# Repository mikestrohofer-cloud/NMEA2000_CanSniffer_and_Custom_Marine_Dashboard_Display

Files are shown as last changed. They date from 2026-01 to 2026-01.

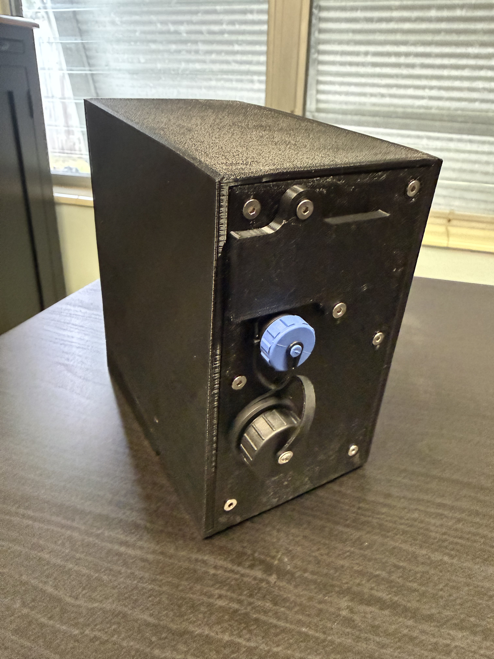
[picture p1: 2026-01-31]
Photos/Display Body 2.jpeg

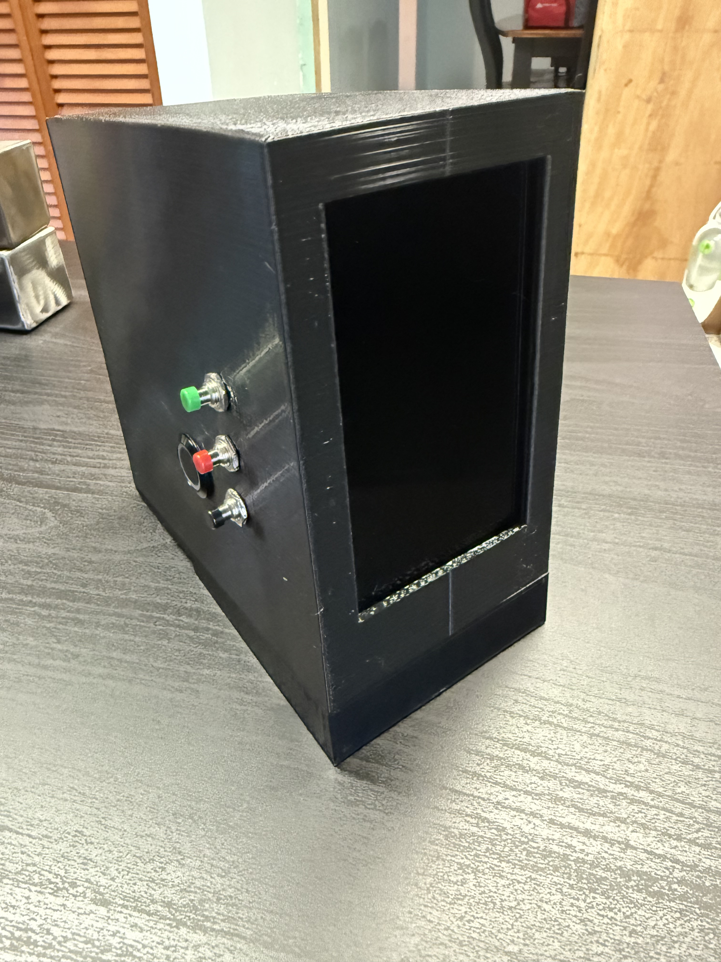
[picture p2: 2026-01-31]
Photos/Display Body 1.jpeg

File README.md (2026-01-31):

# CanSniffer & Mini Screen Build (MK1)

Hi, 

Welcome to CanSniffer & Mini Screen build MK1, this project came from the desire to interact with my boat’s network, sniff data and display on my own custom screen with custom graphics. 
NOTE: This was all ChatGPT vibe coded, I am not a software engineer, I’m more of a 12V electronics / Cad guy who was feeling like trying something new. As a result this code is likely not optimized and not fit for commercial use. Please use it at your own risk and
DO NOT USE THIS HARDWARE OR CODE FOR ANY CRITICAL INSTUMENTATION DISPLAYS

Now that’s out of the way, the system architecture is split into 2 halves, the Arduino based CanSniffer takes the data off the NMEA2000 Network, using a CAN reading card, grabs data out of the relevant PGN’s and finally outputs a CSV string over USB of 4 values that the Pi is expecting to display on the UI.  

Currently it is set up for single frame reading of the Trim % and RPM PGN. It uses fast packet to decode the PGN for fuel consumption rate and it uses FF12 which is proprietary SUZUKI PGN used for shift indication. That PGN was decoded during the DEV process for my specific setup of a single Fly-by-wire shift and throttle controller, one SMG4 MFD and a DF200 single outboard. This may or may not work with other setups of SUZUKI hardware.This is an experimental hobby project, not production-grade, as I said before and chatgpt handled the code work on this project. I recommend having a laptop collecting the log data when using the software. There is also a little I2C OLED screen on the CanSniffer itself you can use for whatever. 

In the PI I have some helper scipts that work with the 3 buttons on the side of the display case, the references to the name of the main code for the pi display is called PiRudderTach.py you can change that but you will have to adjust everything in the support sofware, the screen also needs to be configured in the PI for portait orientation

In my experience this build has been stable and I am happy with it, of course anyone who has more experience will be able to add features or optimizations. Good luck, I would love to hear from anyone who is working on this project and what you end up making. 

## Getting Started
1. Upload the Arduino sketch to an Arduino Nano  
2. Connect MCP2515 to the NMEA2000 backbone  
3. Plug Arduino into Raspberry Pi via USB  
4. Run the dashboard script on the Pi  

This project was developed and tested on:
- Suzuki DF200 outboard
- Single fly-by-wire shift/throttle controller
- One SMG4 MFD
- Arduino Nano + MCP2515 module
- Small I2C OLED screen on the sniffer unit

The current firmware is configured for:
- **Trim % + RPM** (single-frame decoding)
- **Fuel Rate** (Fast Packet decoding, PGN 127489)
- **Shift / Gear Indicator** via proprietary Suzuki PGN:
- **PGN FF12 (65298)** — Suzuki-specific gear data

## Serial Output Format
The Arduino outputs a 4-field CSV frame over USB:

trim_raw,rpm_raw,gear,fuel_gph
Where `gear` is encoded as:
- `-1` = Reverse  
- `0` = Neutral  
- `1` = Forward  

## Licensing
- Software (Arduino + Pi code): GPL v3  
- Hardware/design files (STLs, wiring): CC BY-SA 4.0

This project is for experimental/educational use only.

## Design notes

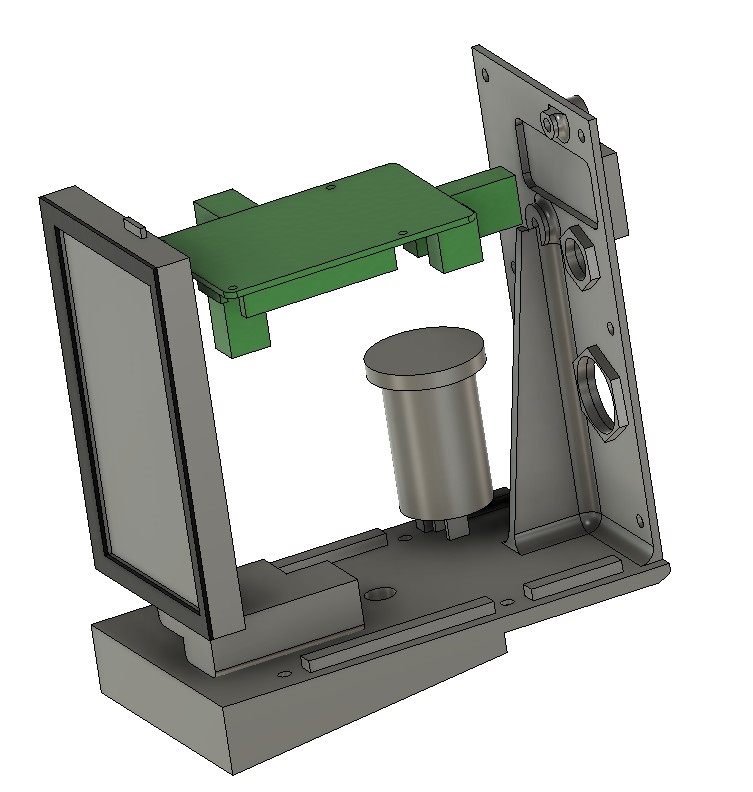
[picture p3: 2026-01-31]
Photos/Mini Screen CAD 2.jpg

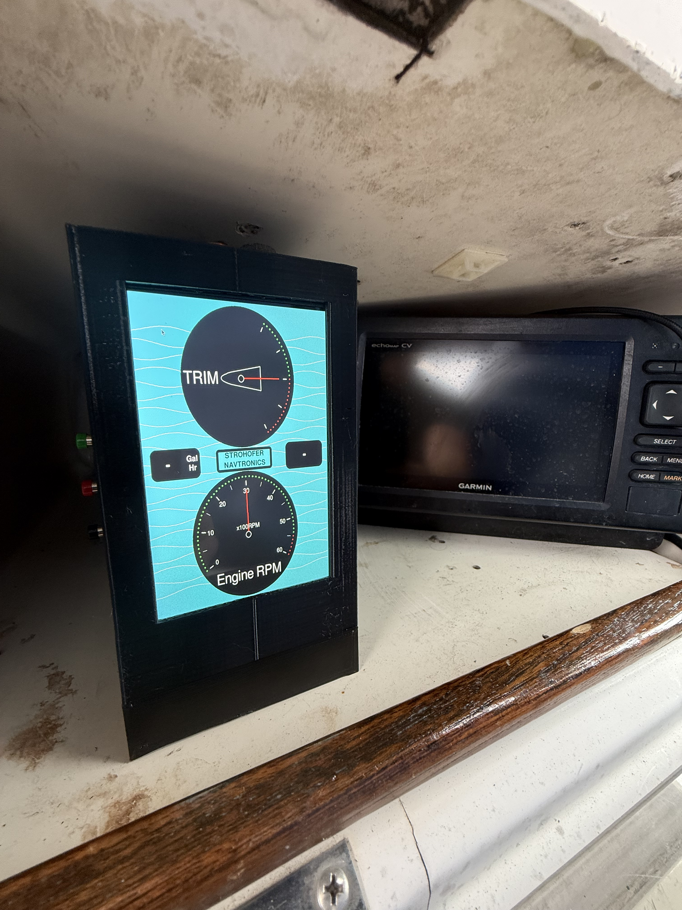
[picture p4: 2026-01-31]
Photos/Display Screen.jpeg

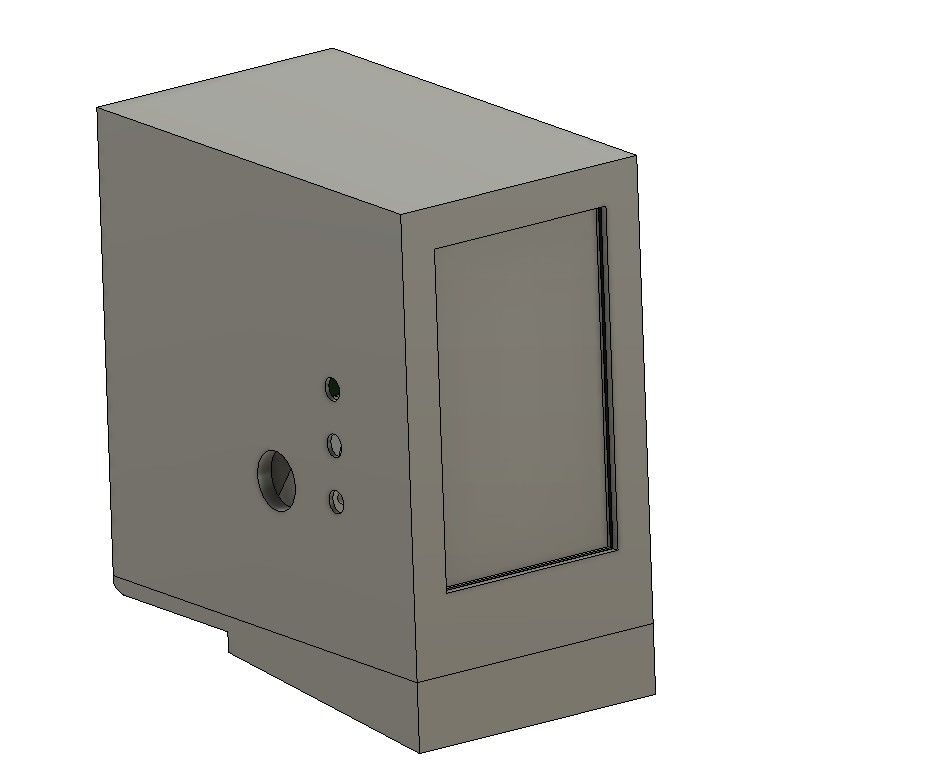
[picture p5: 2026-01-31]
Photos/Mini Screen CAD 1.jpg

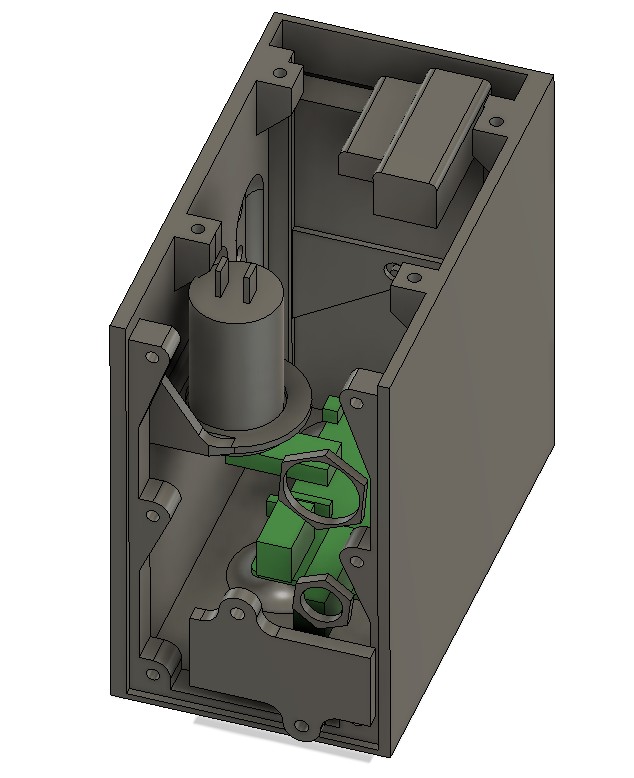
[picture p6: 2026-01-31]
Photos/Mini Screen CAD 3.jpg

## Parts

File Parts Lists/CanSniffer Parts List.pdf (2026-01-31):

# CanSnier Part List

Mini Nano V3.0 ATmega328P

### 5 Pcs 0.96 Inch OLED I2C IIC Display Module 12864 128x64 Pixel SSD1306 Mini Self-

Luminous OLED Screen Board Compatible with Arduino Raspberry Pi

WWZMDiB 3 Pcs MCP2515 TJA1050 CAN Bus Module SPI Interface Compatible with for Arduino Raspberry Pi ESP32 STM (CAN Bus Controller + Receiver)

AITRIP 8 Pack Mini MP1584EN DC-DC Buck Converter Adjustable Power Supply Module 24V to 12V 9V 5V 3VCompatible with Arduino Raspberry Pi

100pcs 5.1K ohm Resistor 1/4w (0.25 Watt) ±1% Tolerance Metal Film Fixed Resistor

DIANN 5pcs USB Type-C Breakout Board Serial Basic Breakout Female Connector Type PCB Converter Board

NMEA2000 Cable (Choose the length you need to get from your T to the can-snier)

QIANRENON 5Gbps USB C Threaded Fixed Short Cable USB Type C 3.0 Male to Female Embedded Charging Data Adapter Cable USB C 3.0 Bulkhead Mount Connector PD 60W 3A, for Furniture/Car/RV, 30cm/11.8in

Fuse Holders (Use a .5 amp)

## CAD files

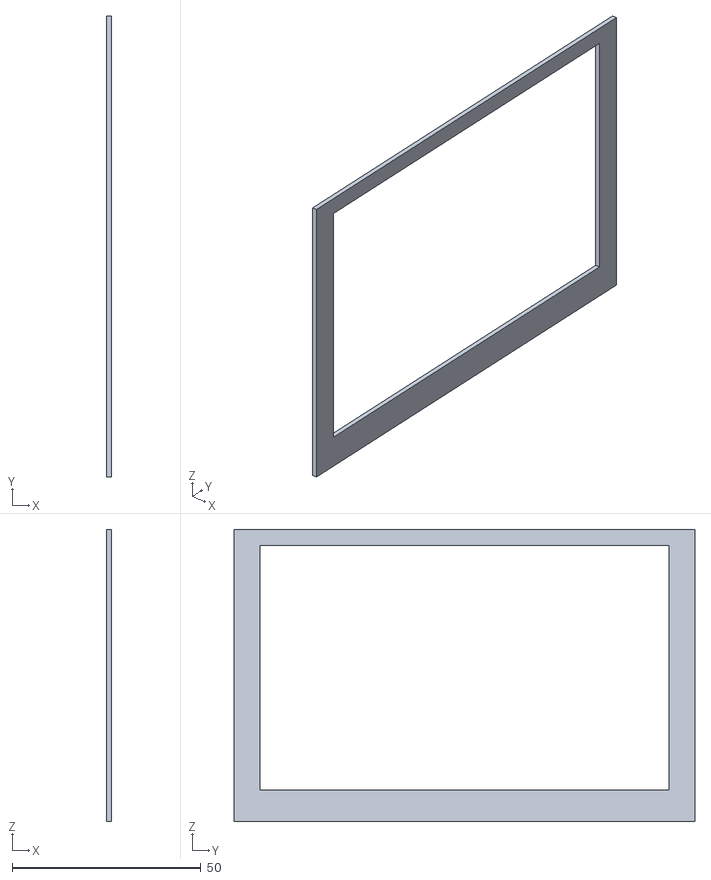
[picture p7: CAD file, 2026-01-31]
3D_Prints/Display Gasket.stl
1.27 x 122.3 x 77.5

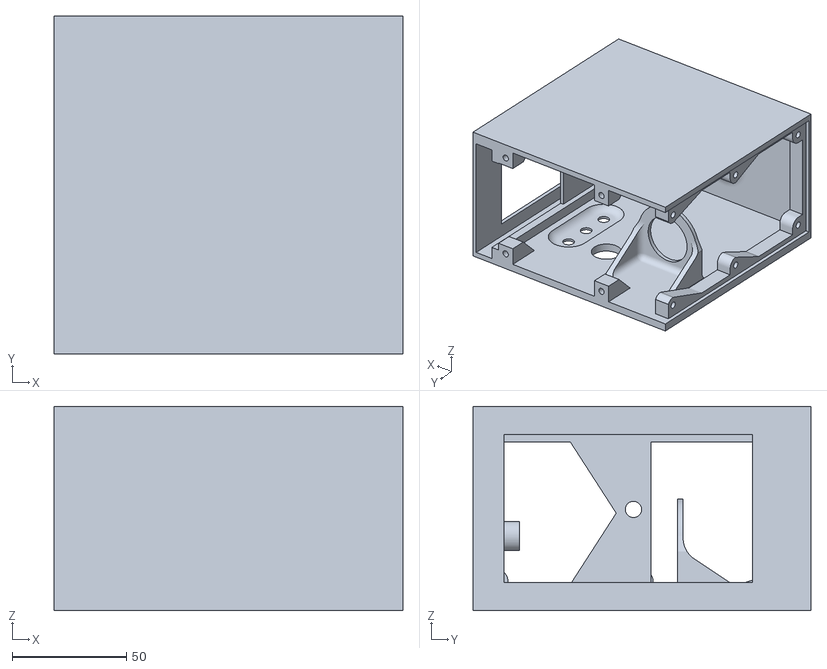
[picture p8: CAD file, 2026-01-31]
3D_Prints/Display Body.stl
152.4 x 147.7 x 89.2

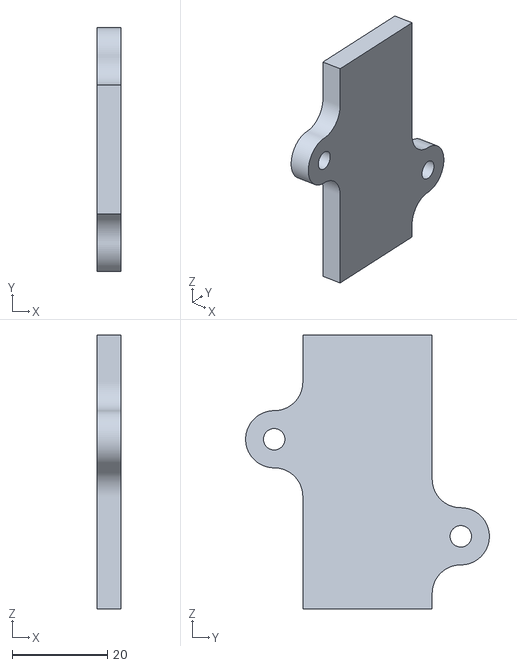
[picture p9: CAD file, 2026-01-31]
3D_Prints/Display PI USB Cover.stl
5.08 x 51.2 x 57.5

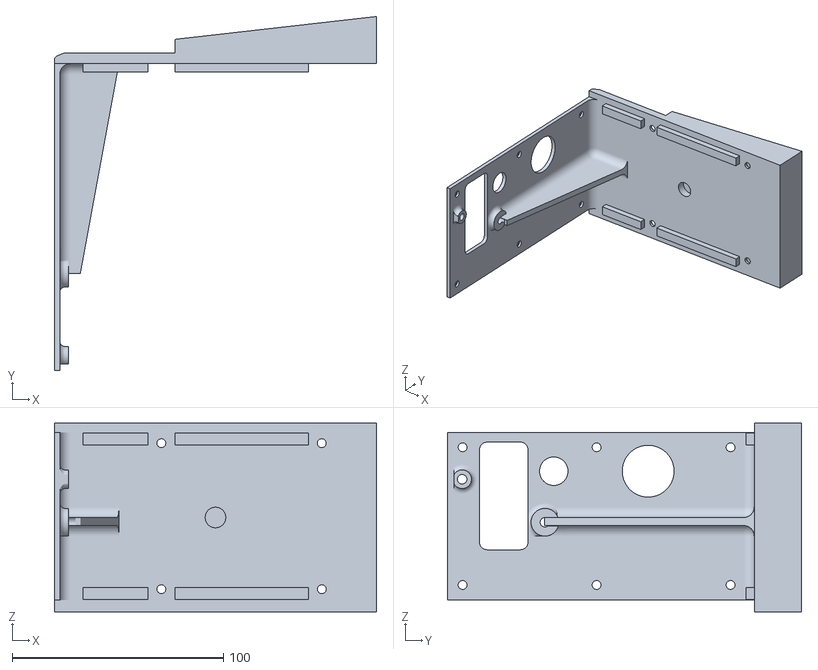
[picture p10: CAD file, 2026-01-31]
3D_Prints/Display Rear Panel.stl
152.4 x 167.5 x 89.2

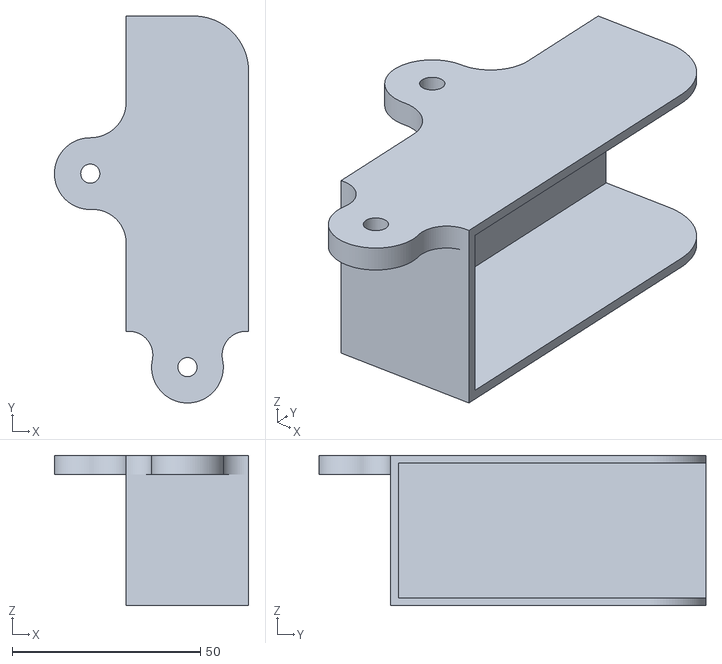
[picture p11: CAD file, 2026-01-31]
3D_Prints/CanSniffer Mount R 3D Print.stl
51.6 x 102.8 x 39.9

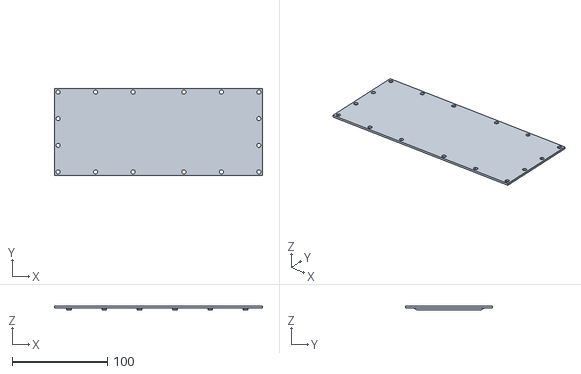
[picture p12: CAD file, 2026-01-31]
3D_Prints/CanSniffer Lid 3D Print.stl
218.4 x 91.4 x 3.81

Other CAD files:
3D_Prints/CanSniffer Mount L 3D Print.stl

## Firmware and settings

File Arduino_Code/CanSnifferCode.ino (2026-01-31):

#include <SPI.h>
#include <mcp_can.h>
#include <U8x8lib.h>

// ================== CONFIG ==================
#define CAN_CS_PIN   10
#define CAN_INT_PIN  2           // MCP2515 INT -> Nano D2
#define CAN_SPEED    CAN_250KBPS
#define CAN_CLOCK    MCP_8MHZ

// OLED text-only (still useful locally)
U8X8_SSD1306_128X64_NONAME_HW_I2C oled(U8X8_PIN_NONE);

// PGNs we care about
static const uint32_t PGN_127489   = 127489UL; // Fuel rate (Fast Packet)
static const uint32_t PGN_SUZ_GEAR = 65298UL;  // Suzuki proprietary (0xFF12)
static const uint32_t PGN_127488   = 127488UL; // Engine params rapid update (you saw trim + RPM here)

// Data freshness (ms)
#define STALE_FUEL_MS 1500UL
#define STALE_GEAR_MS 1000UL

#define OLED_PERIOD_MS 150UL

// CSV output to mini screen
#define CSV_PERIOD_MS 50UL        // 20 Hz
#define CAN_STALE_MS  1000UL      // if CAN stale -> force Neutral / zeroes

// Optional: filter by source address (0xFF = accept any)
#define ENGINE_SA_FILTER 0xFF

// ================== RPM CALIBRATION ==================
// Empirical fix: Suzuki 127488 RPM reads high (~900 shows ~650 actual)
#define RPM_CAL 0.72f

// ================== CAN ==================
MCP_CAN CAN0(CAN_CS_PIN);

// ================== INT FLAG ==================
volatile bool canIntFlag = false;
void onCanInt() { canIntFlag = true; }

// ================== VALUE STATE ==================
volatile float fuel_gph = 0.0f;
volatile char  gearCharV = 'N';      // 'F' 'N' 'R'
volatile uint8_t engine_instance = 0;

volatile int rpm_calibrated = 0;
uint32_t last_rpm_ms = 0;

volatile int trim_percent = -1;      // optional: used for local OLED only
uint32_t last_trim_ms = 0;

uint32_t last_fuel_ms = 0;
uint32_t last_gear_ms = 0;

uint8_t lastSuzB4 = 0x00;

// ================== HELPERS ==================
static inline uint32_t extractPGN(uint32_t canId) {
  uint8_t dp = (canId >> 24) & 0x01;
  uint8_t pf = (canId >> 16) & 0xFF;
  uint8_t ps = (canId >> 8)  & 0xFF;
  uint32_t pgn = ((uint32_t)dp << 16) | ((uint32_t)pf << 8);
  if (pf >= 240) pgn |= ps;
  return pgn;
}

static inline uint8_t extractSA(uint32_t canId) {
  return (uint8_t)(canId & 0xFF);
}

static inline uint16_t u16le(const uint8_t* p) {
  return (uint16_t)p[0] | ((uint16_t)p[1] << 8);
}

static inline int16_t s16le(const uint8_t* p) {
  return (int16_t)u16le(p);
}

// Pi expects: {1:"R", 2:"N", 3:"F"}
static int gearToShiftIndicator(char g) {
  if (g == 'R') return 1;
  if (g == 'N') return 2;
  if (g == 'F') return 3;
  return 2; // safe default Neutral
}

// Suzuki gear decode (proven on your system)
static char decodeSuzukiGearB4(uint8_t b4) {
  if (b4 == 0x7F) return 'N';          // special neutral case
  uint8_t top = b4 & 0xC0;
  if (top == 0xC0) return 'F';
  if (top == 0x80) return 'N';
  if (top == 0x40) return 'R';
  return '?';
}

// ================== 127488 RPM + TRIM ==================
// Note: you're seeing trim% track correctly from this PGN on your Suzuki gateway.
// RPM bytes are standard (bytes 1..2, 0.25 RPM/bit). Trim byte is vendor-ish;
// based on your captures it behaves like 0..100 (byte 5). We'll keep it simple.
static void decode127488_rpm_trim(const uint8_t* d, uint8_t len) {
  if (len < 6) return;

  // RPM: bytes 1..2 little-endian
  uint16_t raw = (uint16_t)d[1] | ((uint16_t)d[2] << 8);
  if (raw != 0xFFFF && raw != 0x7FFF) {
    float rpm = raw * 0.25f;
    rpm *= RPM_CAL;
    rpm_calibrated = (int)(rpm + 0.5f);
    last_rpm_ms = millis();
  }

  // TRIM: based on your logs, byte 5 tracks 0..100-ish.
  // If it ever goes 0xFF, treat as invalid.
  uint8_t t = d[5];
  if (t != 0xFF) {
    trim_percent = (int)t;
    last_trim_ms = millis();
  }
}

// ================== FAST PACKET (127489) ==================
struct FastPacket {
  bool active = false;
  uint8_t sa = 0xFF;
  uint8_t seq = 0;
  uint8_t expectedLen = 0;
  uint8_t buf[32];
  uint8_t filled = 0;
  uint32_t lastMs = 0;

  void reset() { active=false; sa=0xFF; seq=0; expectedLen=0; filled=0; lastMs=0; }

  void begin(uint8_t _sa, uint8_t _seq, uint8_t totalLen, const uint8_t* frame) {
    reset();
    active = true; sa=_sa; seq=_seq; expectedLen=totalLen; lastMs=millis();
    uint8_t toCopy = 6;
    if (toCopy > expectedLen) toCopy = expectedLen;
    for (uint8_t i=0;i<toCopy;i++) buf[i] = frame[2+i];
    filled = toCopy;
  }

  void add(uint8_t _sa, uint8_t _seq, uint8_t frameIdx, const uint8_t* frame) {
    if (!active) return;
    if (_sa != sa) return;
    if (_seq != seq) return;
    lastMs = millis();

    uint16_t base = 6 + (uint16_t)(frameIdx - 1) * 7;
    if (base >= expectedLen) return;

    uint8_t toCopy = 7;
    if (base + toCopy > expectedLen) toCopy = expectedLen - base;
    for (uint8_t i=0;i<toCopy;i++) buf[base+i] = frame[1+i];

    uint16_t newFilled = base + toCopy;
    if (newFilled > filled) filled = (uint8_t)newFilled;
  }

  bool complete() const { return active && expectedLen > 0 && filled >= expectedLen; }
};

FastPacket fp489;

static void decode127489_payload(const uint8_t* p, uint8_t n) {
  if (n < 11) return;
  engine_instance = p[0];

  // Fuel rate at payload offset 9..10, 0.1 L/h signed
  int16_t fuel_raw = s16le(&p[9]);

  // NA guards
  if (fuel_raw == (int16_t)0x7FFF || fuel_raw == -1) return;

  float fuel_Lph = fuel_raw * 0.1f;
  if (fuel_Lph < 0) fuel_Lph = 0;

  fuel_gph = fuel_Lph * 0.264172052f; // L/h -> GPH
  last_fuel_ms = millis();
}

static void handle127489_frame(uint8_t sa, const uint8_t* d, uint8_t len) {
  if (len < 8) return;

  if (fp489.active && (millis() - fp489.lastMs) > 250UL) fp489.reset();

  uint8_t hdr = d[0];
  uint8_t seq = (hdr >> 5) & 0x07;
  uint8_t frameIdx = hdr & 0x1F;

  if (frameIdx == 0) {
    uint8_t totalLen = d[1];
    if (totalLen > sizeof(fp489.buf)) { fp489.reset(); return; }
    fp489.begin(sa, seq, totalLen, d);
  } else {
    fp489.add(sa, seq, frameIdx, d);
  }

  if (fp489.complete()) {
    decode127489_payload(fp489.buf, fp489.expectedLen);
    fp489.reset();
  }
}

// ================== SUZUKI GEAR (65298) ==================
static void decodeSuzukiGear(const uint8_t* d, uint8_t len) {
  if (len < 5) return; // we use d[4]
  lastSuzB4 = d[4];
  char g = decodeSuzukiGearB4(lastSuzB4);
  if (g == 'F' || g == 'N' || g == 'R') {
    gearCharV = g;
    last_gear_ms = millis();
  }
}

// ================== OLED ==================
static void oledBoot(const char* l1, const char* l2) {
  oled.clear();
  oled.drawString(0, 0, l1);
  oled.drawString(0, 2, l2);
}

static void oledRender() {
  uint32_t now = millis();
  bool fuel_stale = (now - last_fuel_ms) > STALE_FUEL_MS;
  bool gear_stale = (now - last_gear_ms) > STALE_GEAR_MS;
  bool rpm_stale  = (now - last_rpm_ms)  > CAN_STALE_MS;

  char line0[17], line2[17], line4[17], line6[17];

  if (fuel_stale) snprintf(line0, sizeof(line0), "FUEL: ---- GPH");
  else {
    int whole = (int)fuel_gph;
    int frac  = (int)((fuel_gph - whole) * 100.0f + 0.5f);
    if (frac < 0) frac = 0;
    if (frac > 99) frac = 99;
    snprintf(line0, sizeof(line0), "FUEL:%d.%02d GPH", whole, frac);
  }

  if (gear_stale) snprintf(line2, sizeof(line2), "GEAR:? RPM:----");
  else {
    char gbuf[2] = { gearCharV, 0 };
    if (rpm_stale) snprintf(line2, sizeof(line2), "GEAR:%s RPM:----", gbuf);
    else snprintf(line2, sizeof(line2), "GEAR:%s RPM:%4d", gbuf, rpm_calibrated);
  }

  // Show trim on line4
  if ((now - last_trim_ms) > CAN_STALE_MS || trim_percent < 0) {
    snprintf(line4, sizeof(line4), "TRIM: --%%  B4:%02X", lastSuzB4);
  } else {
    int tp = trim_percent;
    if (tp < 0) tp = 0;
    if (tp > 100) tp = 100;
    snprintf(line4, sizeof(line4), "TRIM:%3d%% B4:%02X", tp, lastSuzB4);
  }

  snprintf(line6, sizeof(line6), "AGE F:%lu G:%lu",
           fuel_stale ? 9999UL : (unsigned long)(now - last_fuel_ms),
           gear_stale ? 9999UL : (unsigned long)(now - last_gear_ms));

  oled.clear();
  oled.drawString(0, 0, line0);
  oled.drawString(0, 2, line2);
  oled.drawString(0, 4, line4);
  oled.drawString(0, 6, line6);
}

// ================== CAN DRAIN ==================
static void processCAN() {
  unsigned long rxId = 0;
  unsigned char len = 0;
  unsigned char buf[8];

  while (CAN0.checkReceive() == CAN_MSGAVAIL) {
    CAN0.readMsgBuf(&rxId, &len, buf);

    uint32_t id = (uint32_t)rxId;
    uint8_t sa = extractSA(id);
    if (ENGINE_SA_FILTER != 0xFF && sa != ENGINE_SA_FILTER) continue;

    uint32_t pgn = extractPGN(id);

    if (pgn == PGN_127489) {
      handle127489_frame(sa, buf, len);
    } else if (pgn == PGN_SUZ_GEAR) {
      decodeSuzukiGear(buf, len);
    } else if (pgn == PGN_127488) {
      decode127488_rpm_trim(buf, len);
    }
  }
}

// ================== CSV OUTPUT ==================
static void sendCSV() {
  // Your mini screen expects 4 fields:
  // rudder_raw,rpm_raw,shift_indicator,fuel_gph

  // Map TRIM% (0..100) -> "rudder_raw" (0..4095) so your Pi can reuse rudder gauge
  int rudder_raw = 2047; // safe default centered
  if (millis() - last_trim_ms <= CAN_STALE_MS && trim_percent >= 0) {
    int tp = trim_percent;
    if (tp < 0) tp = 0;
    if (tp > 100) tp = 100;
    rudder_raw = (tp * 4095L) / 100L;
  }

  // RPM to "rpm_raw"
  int rpm_raw = (millis() - last_rpm_ms > CAN_STALE_MS) ? 0 : rpm_calibrated;

  // If gear CAN is stale, force Neutral
  if (millis() - last_gear_ms > CAN_STALE_MS) {
    gearCharV = 'N';
  }
  int shift_indicator = gearToShiftIndicator(gearCharV);

  // If fuel is stale, send 0.0
  float fuelOut = (millis() - last_fuel_ms > STALE_FUEL_MS) ? 0.0f : fuel_gph;

  Serial.print(rudder_raw);
  Serial.print(',');
  Serial.print(rpm_raw);
  Serial.print(',');
  Serial.print(shift_indicator);
  Serial.print(',');
  Serial.println(fuelOut, 3);
}

// ================== MAIN ==================
void setup() {
  // IMPORTANT: mini screen baud
  Serial.begin(57600);
  delay(200);

  // Prime the mini screen with valid frames immediately
  for (uint8_t i = 0; i < 20; i++) {
    Serial.println(F("2047,0,2,0.000"));
    delay(20);
  }

  oled.begin();
  oled.setFont(u8x8_font_chroma48medium8_r);
  oledBoot("N2K GAUGE", "Boot...");

  pinMode(CAN_INT_PIN, INPUT_PULLUP);

  // CAN init with retries
  uint32_t t0 = millis();
  bool canOk = false;
  while (millis() - t0 < 5000UL) {
    if (CAN0.begin(MCP_ANY, CAN_SPEED, CAN_CLOCK) == CAN_OK) { canOk = true; break; }
    delay(200);
  }

  if (canOk) {
    // Accept-all (avoid mystery filter state)
    CAN0.init_Mask(0, 1, 0x00000000);
    CAN0.init_Mask(1, 1, 0x00000000);
    for (uint8_t i = 0; i < 6; i++) CAN0.init_Filt(i, 1, 0x00000000);

    CAN0.setMode(MCP_NORMAL);

    attachInterrupt(digitalPinToInterrupt(CAN_INT_PIN), onCanInt, FALLING);
    oledBoot("CAN OK", "CSV live");
  } else {
    oledBoot("CAN FAIL", "CSV live");
  }

  last_fuel_ms = last_gear_ms = last_rpm_ms = last_trim_ms = 0;
}

void loop() {
  if (canIntFlag) {
    canIntFlag = false;
    processCAN();
  }
  // Safety drain
  processCAN();

  // OLED refresh
  static uint32_t lastOledMs = 0;
  uint32_t now = millis();
  if (now - lastOledMs >= OLED_PERIOD_MS) {
    lastOledMs = now;
    oledRender();
  }

  // CSV output for mini screen
  static uint32_t lastCsv = 0;
  if (now - lastCsv >= CSV_PERIOD_MS) {
    lastCsv = now;
    sendCSV();
  }
}

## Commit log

2026-01-31 Rename CanSniffer Lid 3D Print.stl to 3D_prints/CanSniffer Lid 3D Print.stl
    [CanSniffer Lid 3D Print.stl]
2026-01-31 Rename CanSniffer Mount L 3D Print.stl to 3D_Prints/CanSniffer Mount L 3D Print.stl
    [CanSniffer Mount L 3D Print.stl]
2026-02-11 Arduino Firmware Update
    This is an updated version of the arduino code that no longer 0's out the RPM and fuel consumption values if there is an issue or delay in the PGN decoding. Overall big stability upgrade for the system.
2026-02-11 Rename Arduino_Code/Arduino_Firmware_V1.1 to CanSnifferCodeV1.1
    Firmware Stability Update that no longer 0's out values when there is a PGN decode error
